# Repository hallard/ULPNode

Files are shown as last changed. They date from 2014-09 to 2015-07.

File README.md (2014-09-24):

ULPNode
=======

Utra Low Power Wireless Arduino Node

For some time being, I researching a way to have to have a kind of “universal” Arduino node sensor.  
When I say universal, I’m talking about connecting to it several sensors like Temperature, Humidity, Lux,… such as LDR, NTC, PTC, DHT11, DHT22, DS18B20, I2C sensors.  

At 1st research I tried lot existing, they  works fine, but as soon as you want to power them with classic battery (one AAA, CR2032, …) you’re facing other challenges, be able to maximize the battery life and also be able to send wireless frames until battery is reaching it’s end of life.

##Blog dedicated post
See this [post][2] for detailed and technical information

##License

Copyright Charles-Henri Hallard (2014)  
[Attribution-ShareAlike CC BY-SA][6]

##Misc
Do not hesitate to look on news and other projects on my [blog][1] 
 
[1]: http://hallard.me
[2]: http://hallard.me/bp-ulpnode/
[3]: http://hallard.me/ulpnode-bootloader/
[6]: https://creativecommons.org/licenses/

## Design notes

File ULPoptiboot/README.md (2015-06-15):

ULPNode bootloader
==================

This repo has been moved to use Arduino IDE Boards Manager  
**Please use the new [one][1]**, you will find into ULPNode [bootloader][2]
 
[1]: https://github.com/hallard/Arduino-Boards/
[2]: https://github.com/hallard/Arduino-Boards/tree/master/1.0.0/bootloaders/ULPoptiboot

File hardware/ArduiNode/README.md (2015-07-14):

Arduinode V1.3
==============

Very first early prototype of Utra Low Power Wireless Arduino Node. In fact it's amazing how often I use this board for testing, it runs on 3.3V, has RFM12B RFM69 connector, NRF24 style connector, I2C Oled connector and some sensors connectors.

It does not include the [Low Power][5] engine of ULPNode but it's a really cool testing board.

**This is not the final design**, this board was done to implement 1st testing and POC, it's posted there as reference only and as help on some Arduino Sketch I wrote that I use with this board. It also include 2 little battery power testing board with different version of MCP1640 DC/DC booster.

##Blog dedicated categories
See this [post][4] for detailed and technical information on ULPNode

##License

Copyright Charles-Henri Hallard (2014)  
[Attribution-ShareAlike CC BY-SA][6]

##Misc
Do not hesitate to look on news and other projects on my [blog][1] 

##schematics

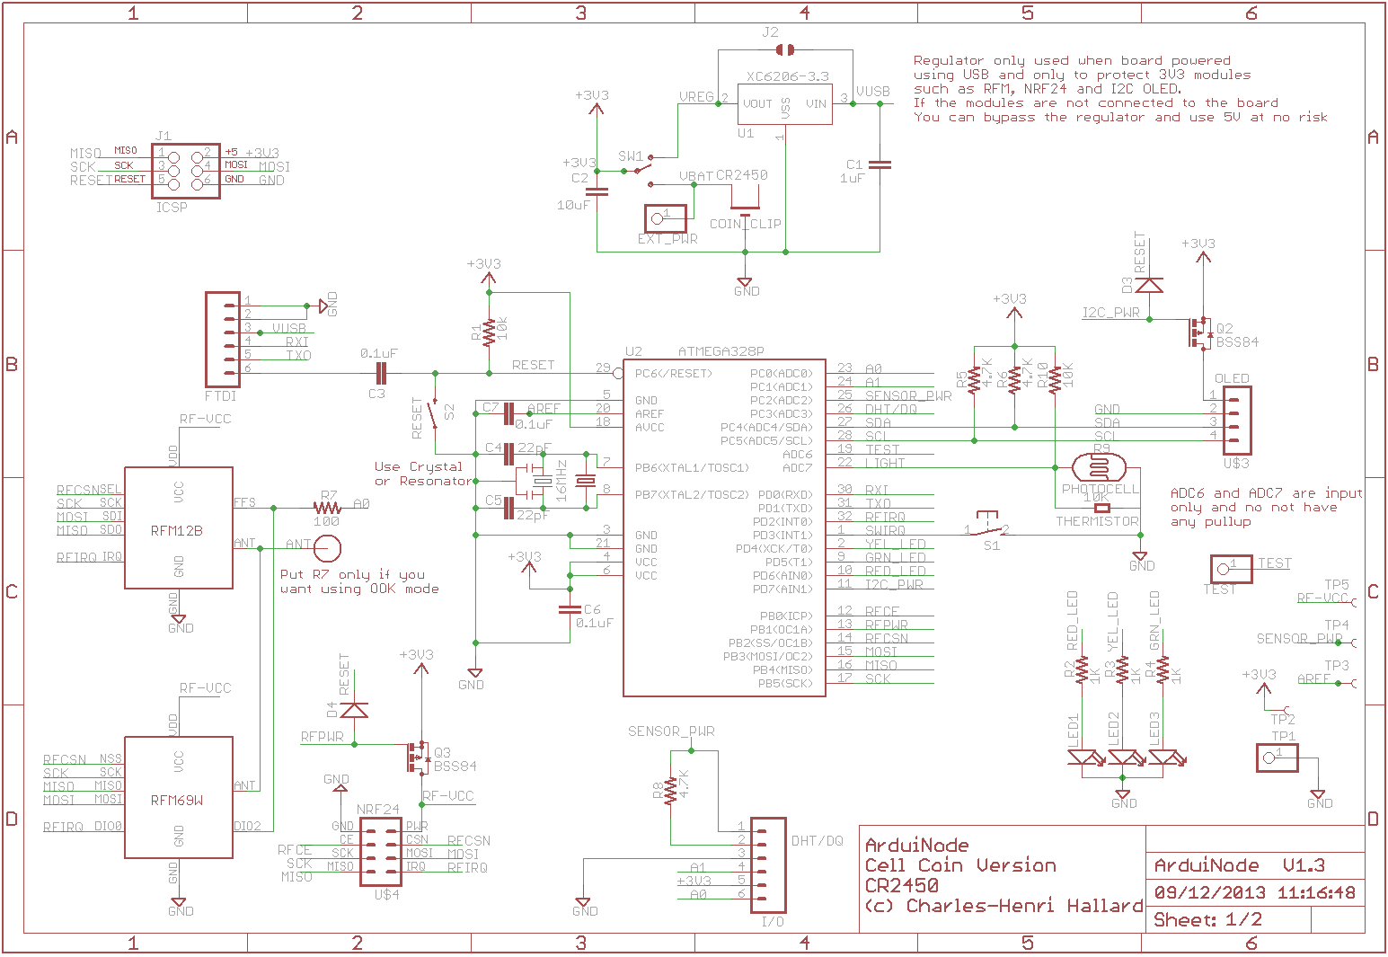
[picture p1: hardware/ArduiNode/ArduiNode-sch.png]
schematic


Do not hesitate to look on news and other projects on my [blog][1] 
 
[1]: http://hallard.me
[2]: http://hallard.me/bp-ulpnode/
[3]: http://hallard.me/ulpnode-bootloader/
[4]: http://hallard.me/category/ulpnode/
[5]: http://hallard.me/ulpnode-low-power-secret/
[6]: https://creativecommons.org/licenses/

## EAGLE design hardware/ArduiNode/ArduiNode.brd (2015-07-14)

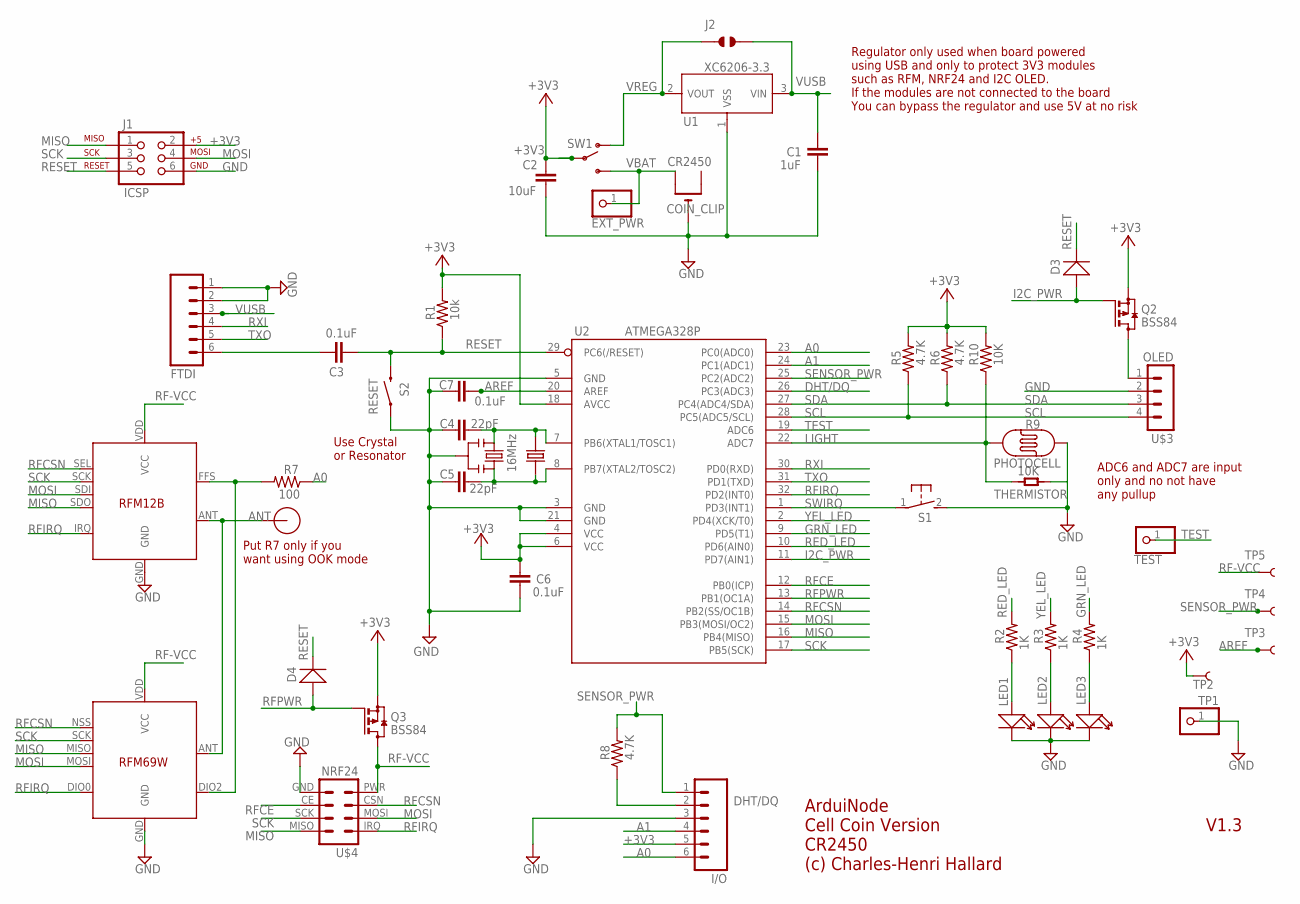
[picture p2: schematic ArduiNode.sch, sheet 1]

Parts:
C1: 1uF; C0805K
C2: 10uF; C0805K
C3, C6, C7: 0.1uF; C0805K
C4, C5: 22pF; C0805K
COIN_CLIP: CR2450; CR1220-THM
D3, D4: D-SOD-123; SOD123
EXT_PWR: PINHD-1X1CB; 1X01-CLEANBIG
FTDI: M06SIP_LOCK; 1X06-SIP_LOCK
I/O: M06FEMALE_LOCK; 1X06_FEMALE_LOCK.010
J1: ICSP; 2X3_LOCK
J2: JUMPER_SOLDER_1X2
LED1, LED2, LED3: LED0805; LED-0805
Q2, Q3: BSS84; SOT23
R1: 10k; M0805
R2, R3, R4: 1K; M0805
R5, R6, R8: 4.7K; M0805
R7: 100; M0805
R9: PHOTOCELL
R10: 10K; M0805
RFM12B: RFM12BNO; RFM12B
S1: DTS-3
S2: RESET; TACTILE-SWITCH-1101NE
SW1: USB_COIN; SWITCH-SPDT-SMD
TEST: PINHD-1X1CB; 1X01-CLEANBIG
THERMISTOR: 10K; R0603
TP1: PINHD-1X1; 1X01
TP2, TP3, TP4, TP5: TEST-POINT3X5; PAD.03X.05
U1: XC6206-3.3; SOT23
U2: ATMEGA328P; TQFP32
U$3: OLED; 1X04_LOCK
U$4: NRF24; 2X04_LOCK
U$11: RFM12B_ANTENNA; RFM12B-ANTENNA
X2: 16MHz; 2P-SMD-5.0X3.2
X3: RFM69; RFM69W-MINPADS
Y1: 16MHz; RESONATOR-SMD

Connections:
+3V3: C2.1, C6.2, I/O.5, J1.2, Q2.2 (S), Q3.2 (S), R1.2, R5.2, R6.2, R10.2, SW1.2, TP2.P$1, U2.4 (VCC), U2.6 (VCC), U2.18 (AVCC)
A0: I/O.6, R7.1, U2.23 (PC0(ADC0))
A1: I/O.4, U2.24 (PC1(ADC1))
ANT: RFM12B.ANT, U$11.P$1, X3.ANT
AREF: C7.1, TP3.P$1, U2.20 (AREF)
DHT/DQ: I/O.2, R8.1, U2.26 (PC3(ADC3))
DTR: C3.1, FTDI.6
GND: C1.2, C2.2, C4.2, C5.2, C6.1, C7.2, COIN_CLIP.GND (-), FTDI.1, FTDI.2, I/O.3, J1.6, LED1.-, LED2.-, LED3.-, R9.1, RFM12B.GND, S1.2, S2.P$1 (1), THERMISTOR.1, TP1.1, U1.1 (VSS), U2.3 (GND), U2.5 (GND), U2.21 (GND), U$3.2, U$4.GND, X3.GND, Y1.2
GRN_LED: R4.2, U2.9 (PD5(T1))
I2C_PWR: D3.+, Q2.1 (G), U2.11 (PD7(AIN1))
LIGHT: R9.2, R10.1, THERMISTOR.2, U2.22 (ADC7)
MISO: J1.1, RFM12B.SDO, U2.16 (PB4(MISO)), U$4.MISO, X3.MISO
MOSI: J1.4, RFM12B.SDI, U2.15 (PB3(MOSI/OC2)), U$4.MOSI, X3.MOSI
unnamed: R7.2, RFM12B.FFS, X3.DIO2
unnamed: LED1.+, R2.1
unnamed: LED2.+, R3.1
unnamed: LED3.+, R4.1
unnamed: Q2.3 (D), U$3.1
RED_LED: R2.2, U2.10 (PD6(AIN0))
RESET: C3.2, D3.-, D4.-, J1.5, R1.1, S2.P$2 (2), U2.29 (PC6(/RESET))
RF-VCC: Q3.3 (D), RFM12B.VDD (VCC), TP5.P$1, U$4.PWR (VCC), X3.VDD (VCC)
RFCE: U2.12 (PB0(ICP)), U$4.CE
RFCSN: RFM12B.SEL, U2.14 (PB2(SS/OC1B)), U$4.CSN, X3.NSS (SEL)
RFIRQ: RFM12B.IRQ, U2.32 (PD2(INT0)), U$4.IRQ, X3.DIO0
RFPWR: D4.+, Q3.1 (G), U2.13 (PB1(OC1A))
RXI: FTDI.4, U2.30 (PD0(RXD))
SCK: J1.3, RFM12B.SCK, U2.17 (PB5(SCK)), U$4.SCK (CLK), X3.SCK
SCL: R5.1, U2.28 (PC5(ADC5/SCL)), U$3.4
SDA: R6.1, U2.27 (PC4(ADC4/SDA)), U$3.3
SENSOR_PWR: I/O.1, R8.2, TP4.P$1, U2.25 (PC2(ADC2))
SWIRQ: S1.1, U2.1 (PD3(INT1))
TEST: TEST.1, U2.19 (ADC6)
TXO: FTDI.5, U2.31 (PD1(TXD))
VBAT: COIN_CLIP.+1 (+), EXT_PWR.1, SW1.1
VREG: J2.1, SW1.3, U1.2 (VOUT)
VUSB: C1.1, FTDI.3, J2.2, U1.3 (VIN)
X1: C5.1, U2.8 (PB7(XTAL2/TOSC2)), X2.1, Y1.3
XTAL1: C4.1, U2.7 (PB6(XTAL1/TOSC1)), X2.2, Y1.1
YEL_LED: R3.2, U2.2 (PD4(XCK/T0))

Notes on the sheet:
V1.3
ArduiNode Cell Coin Version CR2450 (c) Charles-Henri Hallard
Put R7 only if you want using OOK mode
Regulator only used when board powered using USB and only to protect 3V3 modules such as RFM, NRF24 and I2C OLED. If the modules are not connected to the board You can bypass the regulator and use 5V at no risk
ADC6 and ADC7 are input only and no not have any pullup
Use Crystal or Resonator

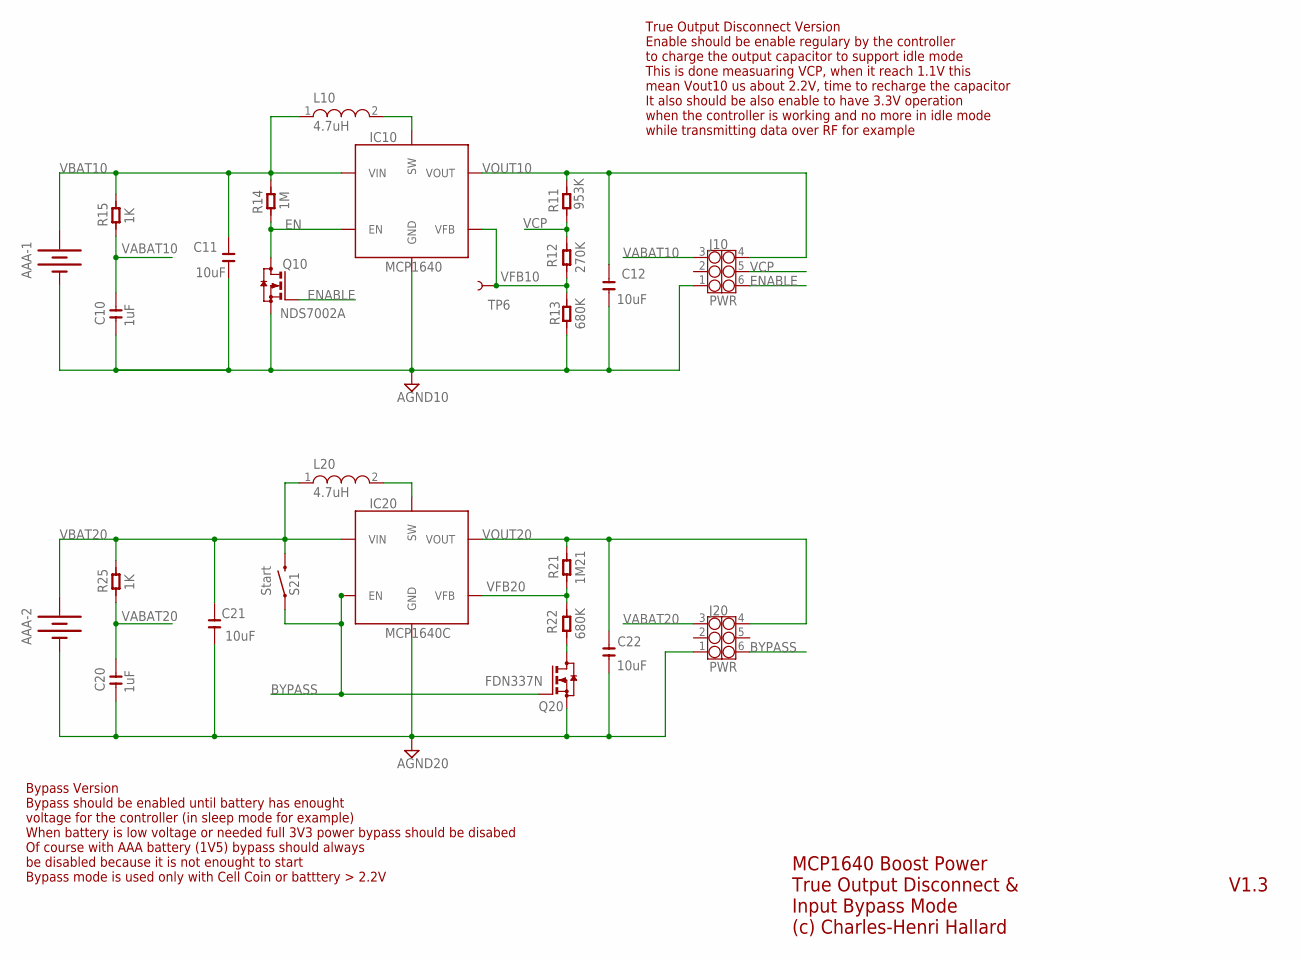
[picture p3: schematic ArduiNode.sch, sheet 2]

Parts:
AAA-1, AAA-2: BATTERYAAA-JL; BATTERY-AAA-JL
C10, C20: 1uF; C0805
C11, C12, C21, C22: 10uF; C0805
IC10: MCP1640; SOT23-6
IC20: MCP1640C; SOT23-6
J10, J20: PWR; 2X3P-2.54-2.54-11.6-3.0-BLACK-MALE
L10, L20: 4.7uH; L1812
Q10: NDS7002A; SOT23
Q20: FDN337N; SOT23
R11: 953K; R0603
R12: 270K; R0603
R13, R22: 680K; R0603
R14: 1M; R0603
R15, R25: 1K; R0603
R21: 1M21; R0603
S21: Start; TACTILE-SWITCH-1101NE
TP6: TEST-POINT3; PAD.03X.03

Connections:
AGND10: AAA-1.GND@1 (-), C10.1, C11.1, C12.1, IC10.2 (GND), J10.1, Q10.2 (S), R13.1
AGND20: AAA-2.GND@1 (-), C20.1, C21.1, C22.1, IC20.2 (GND), J20.1, Q20.2 (S)
BYPASS: IC20.3 (EN), J20.6, Q20.1 (G), S21.P$1 (1)
EN: IC10.3 (EN), Q10.3 (D), R14.1
ENABLE: J10.6, Q10.1 (G)
unnamed: Q20.3 (D), R22.1
SW: IC10.1 (SW), L10.2
SW20: IC20.1 (SW), L20.2
VABAT10: C10.2, J10.3, R15.1
VABAT20: C20.2, J20.3, R25.1
VBAT10: AAA-1.PWR@1 (+), C11.2, IC10.6 (VIN), L10.1, R14.2, R15.2
VBAT20: AAA-2.PWR@1 (+), C21.2, IC20.6 (VIN), L20.1, R25.2, S21.P$2 (2)
VCP: J10.5, R11.1, R12.2
VFB10: IC10.4 (VFB), R12.1, R13.2, TP6.P$1
VFB20: IC20.4 (VFB), R21.1, R22.2
VOUT10: C12.2, IC10.5 (VOUT), J10.4, R11.2
VOUT20: C22.2, IC20.5 (VOUT), J20.4, R21.2

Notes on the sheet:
MCP1640 Boost Power True Output Disconnect & Input Bypass Mode (c) Charles-Henri Hallard
True Output Disconnect Version Enable should be enable regulary by the controller to charge the output capacitor to support idle mode This is done measuaring VCP, when it reach 1.1V this mean Vout10 us about 2.2V, time to recharge the capacitor It also should be also enable to have 3.3V operation w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
Bypass Version Bypass should be enabled until battery has enought voltage for the controller (in sleep mode for example) When battery is low voltage or needed full 3V3 power bypass should be disabed Of course with AAA battery (1V5) bypass should always be disabled because it is not enought to start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
V1.3

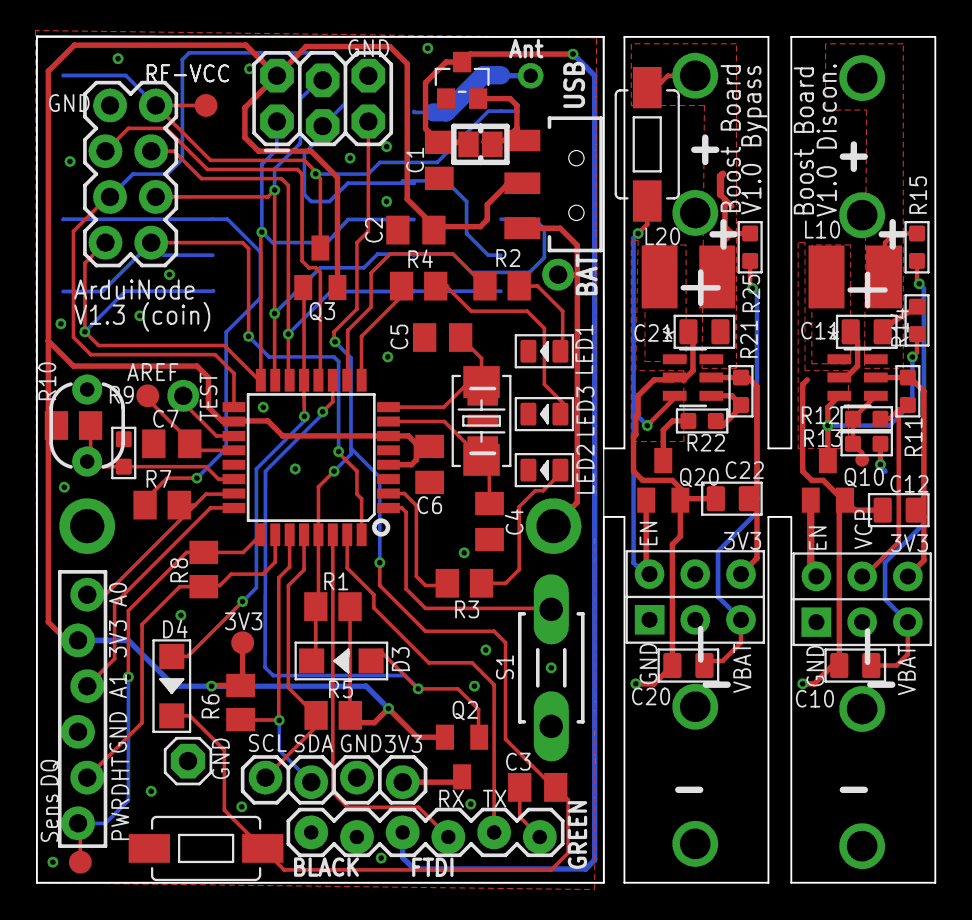
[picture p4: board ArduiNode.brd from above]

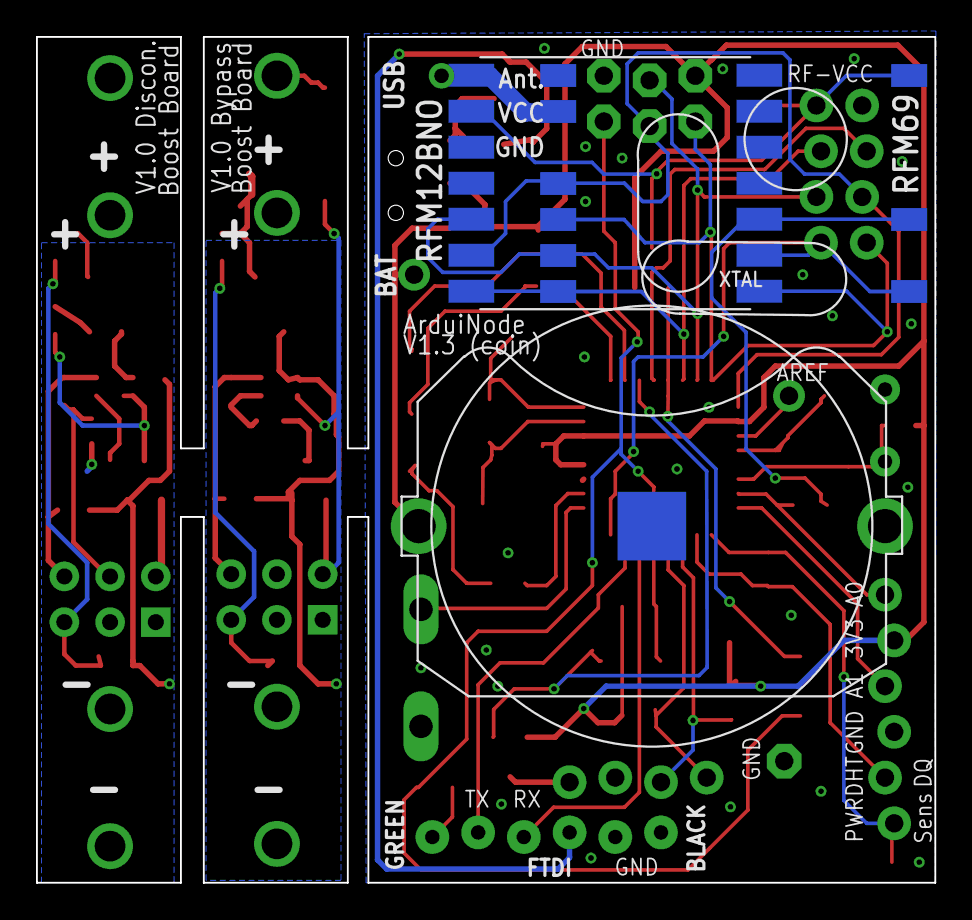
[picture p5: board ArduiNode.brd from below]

Board: 2 copper layers, 49.9 x 47.0 mm, 75 parts (3 on the bottom side), 56 nets.

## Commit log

2014-09-24 Modified for ULPNode
    First commit, modified for ULPNode, added sample sketch to call
    bootloader function
2015-07-14 Creation
    published as reference only
    [ArduiNode.brd, ArduiNode.sch]
2015-07-14 Added schematics image

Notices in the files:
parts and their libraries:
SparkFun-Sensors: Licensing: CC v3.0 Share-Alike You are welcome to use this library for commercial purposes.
